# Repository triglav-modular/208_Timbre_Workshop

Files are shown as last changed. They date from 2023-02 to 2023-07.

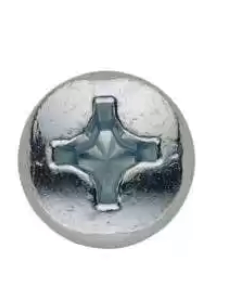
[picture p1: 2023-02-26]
Graphics/Links/208_timbre_2_6.png

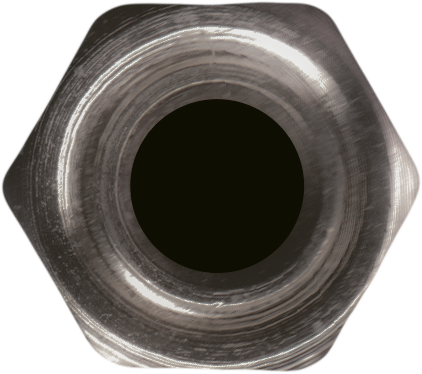
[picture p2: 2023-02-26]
Graphics/Links/208_timbre_2_4.png

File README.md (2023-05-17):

# 208 Timbre Workshop

Eurorack adaptation of the late 208 wavefolder section.

8 HP, adjustable input and output range.

208_Timbre_Workshop

BOM / Mouser cart: 
https://www.mouser.com/ProjectManager/ProjectDetail.aspx?AccessID=5e38aa6b9c

Sliders: https://hu.farnell.com/en-HU/alps/rs4511150k/potentiometer-slide-50k/dp/1191730

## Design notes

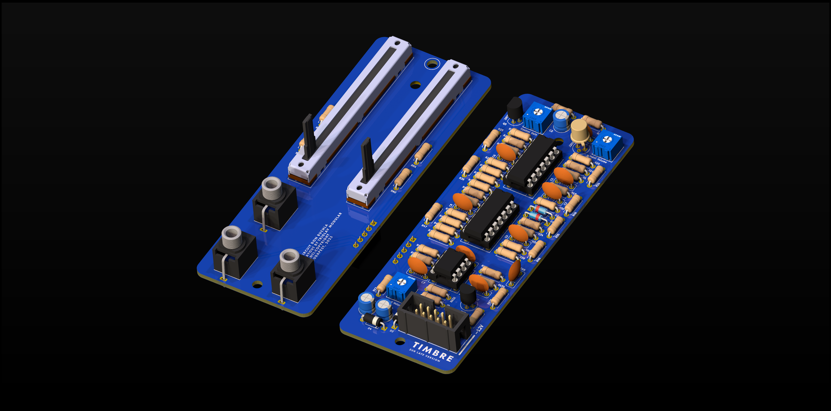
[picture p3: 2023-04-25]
Images/208_Timbre_Workshop.png

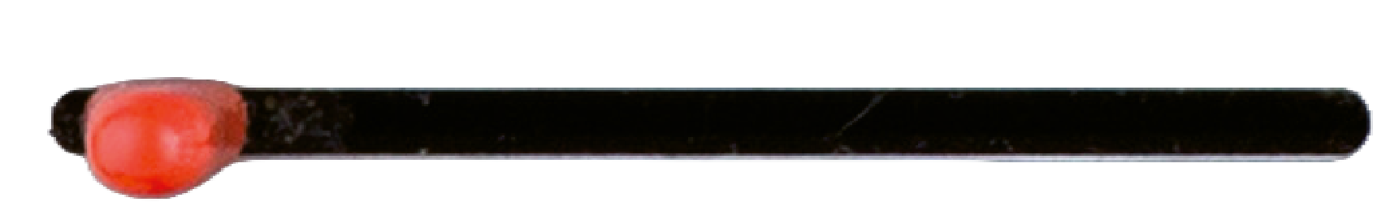
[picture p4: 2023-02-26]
Graphics/Links/208_timbre_2_1.png

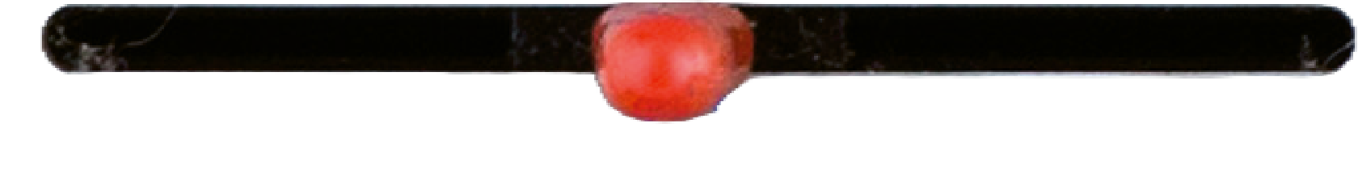
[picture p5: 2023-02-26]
Graphics/Links/208_timbre_2_2.png

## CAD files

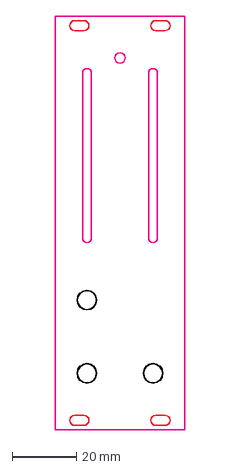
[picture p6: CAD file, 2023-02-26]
Graphics/panel_cut.dxf
40.3 x 128.5 mm

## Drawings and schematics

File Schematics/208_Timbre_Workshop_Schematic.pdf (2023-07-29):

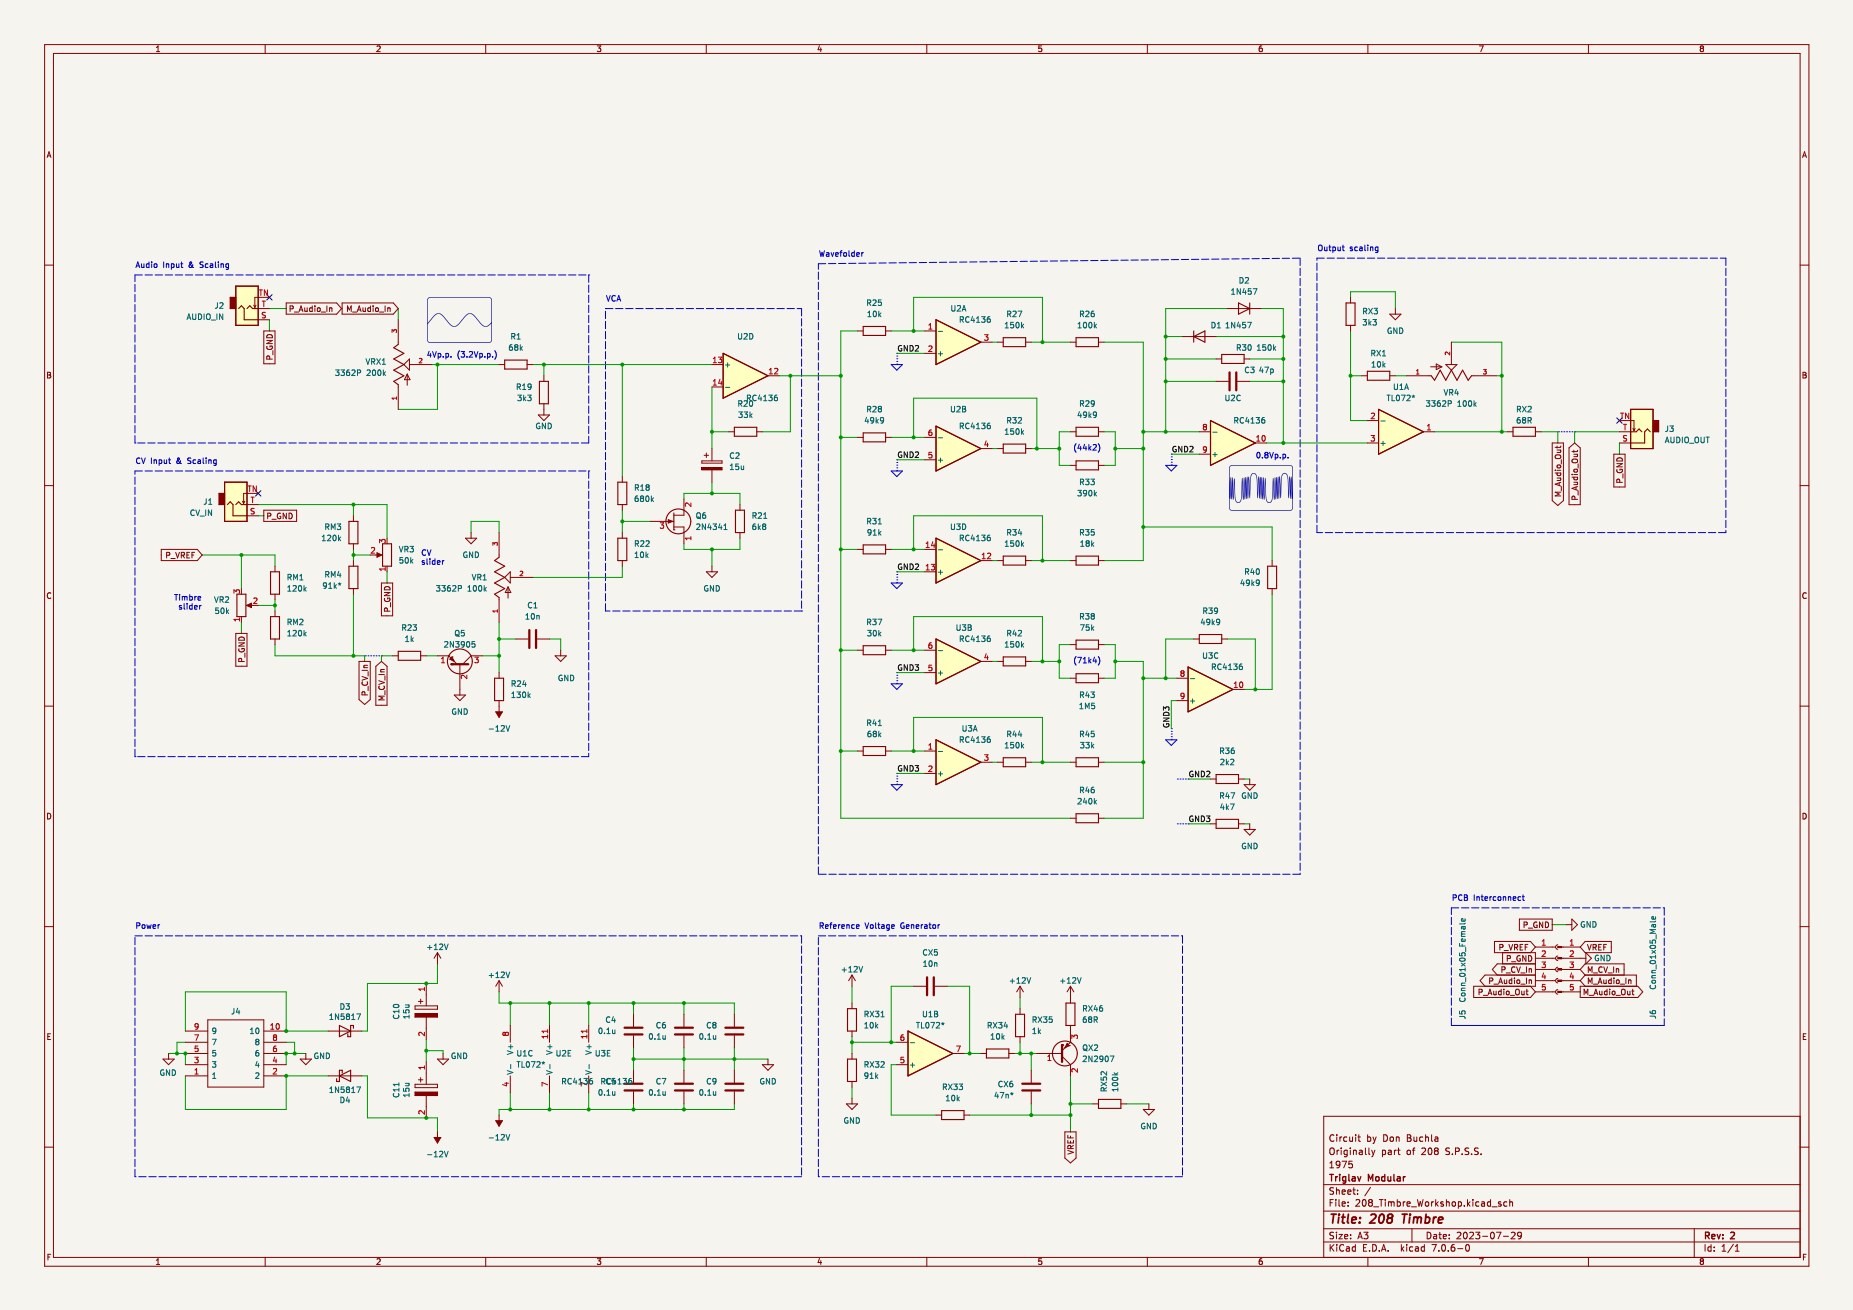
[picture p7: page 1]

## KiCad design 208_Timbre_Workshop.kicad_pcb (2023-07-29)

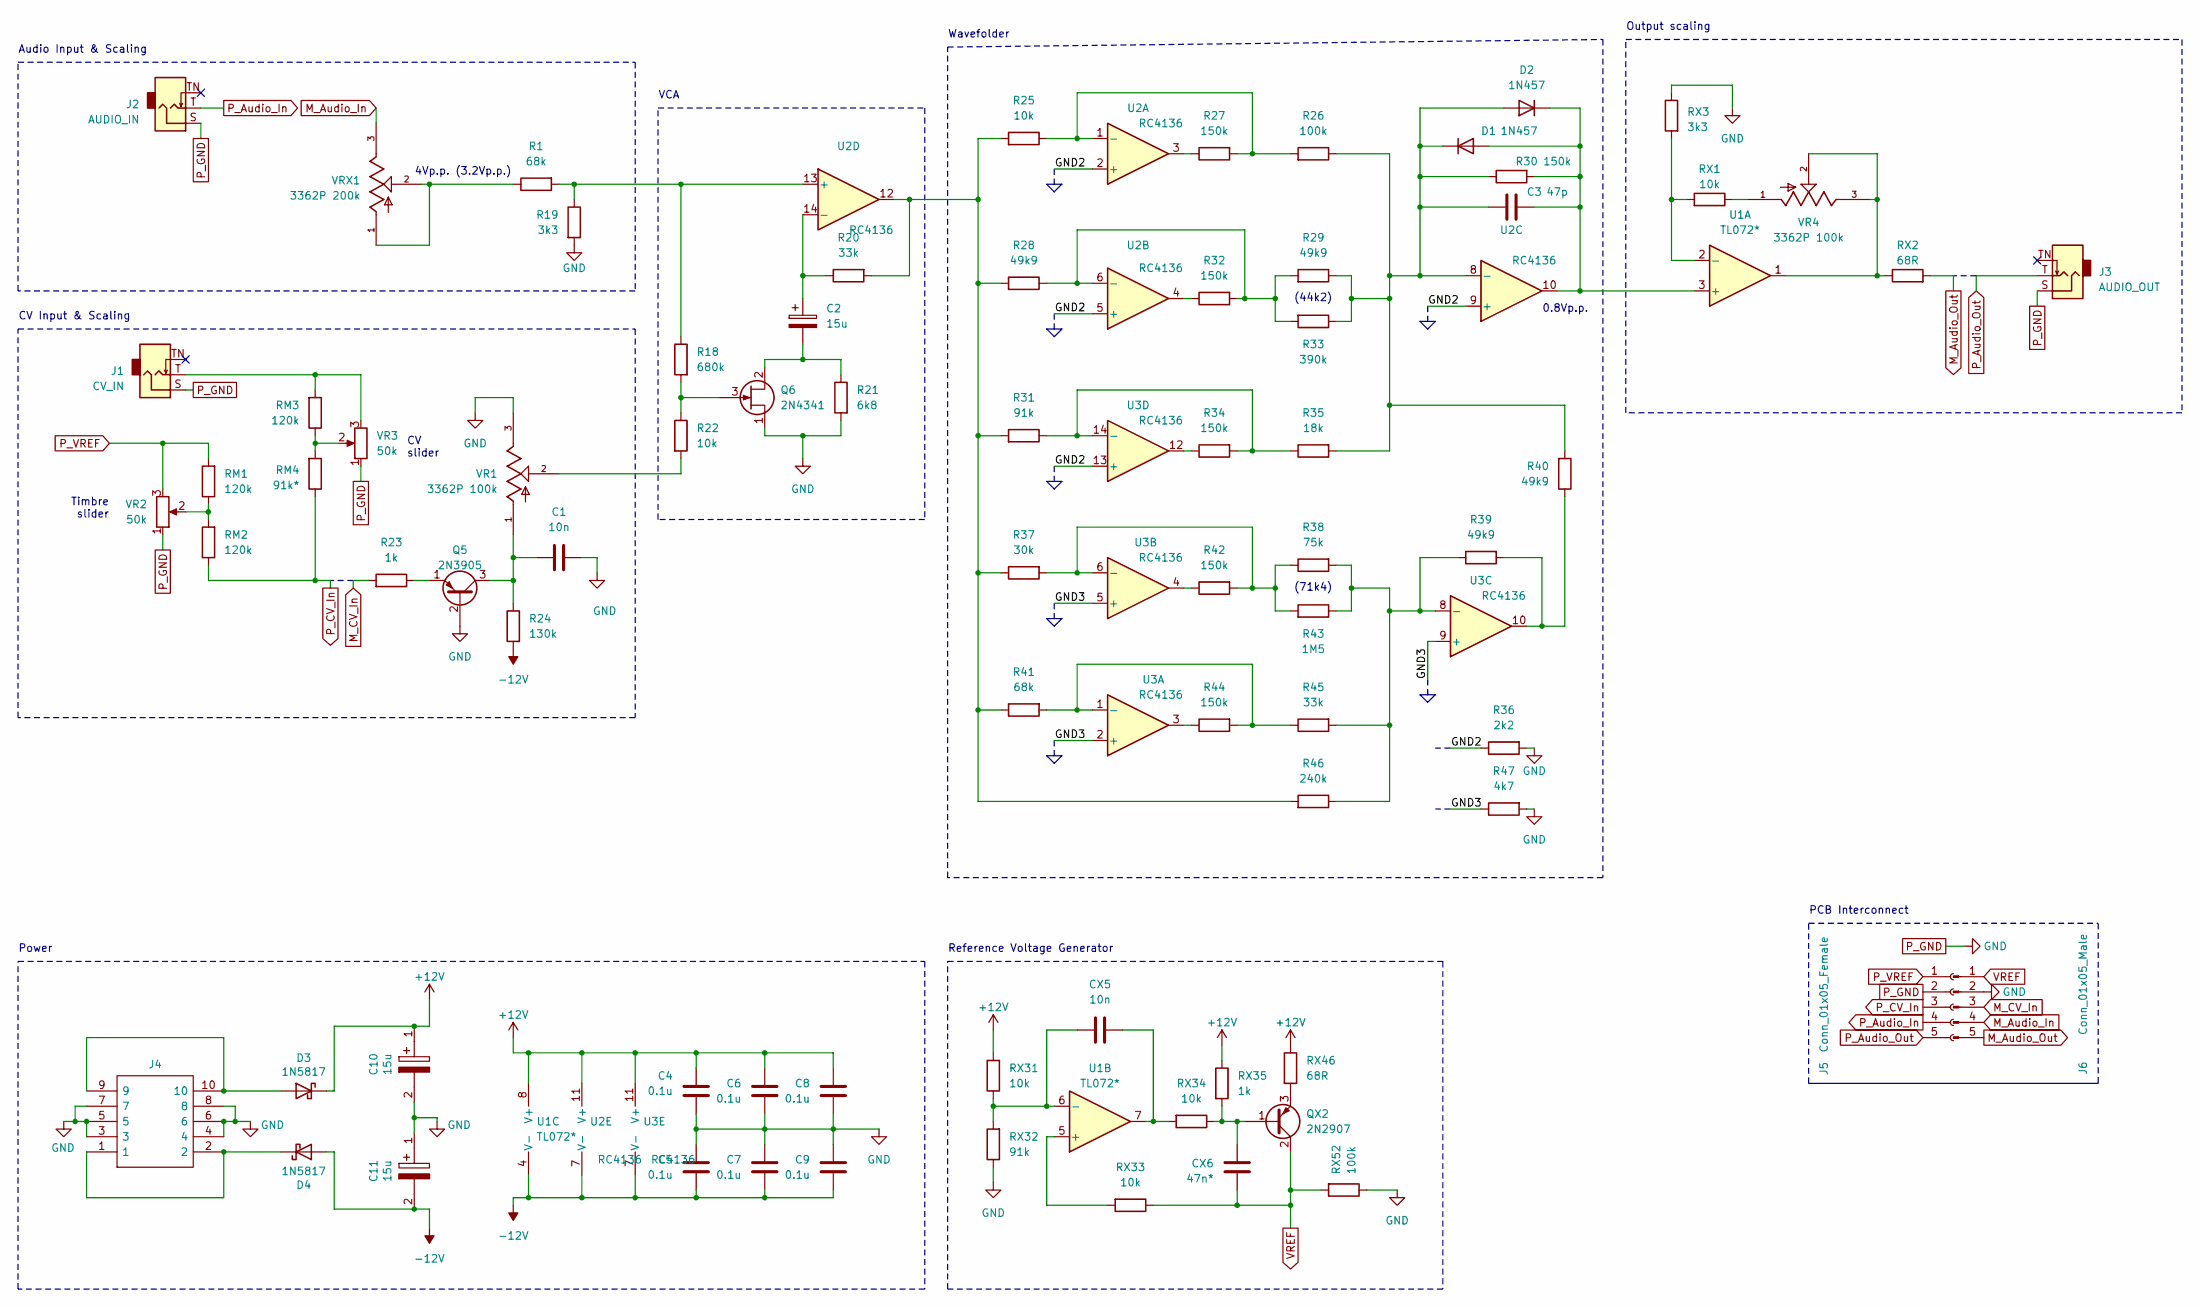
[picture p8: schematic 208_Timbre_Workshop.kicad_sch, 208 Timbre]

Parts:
C1: 10n; C_Disc_D7.0mm_W2.5mm_P5.00mm
C2: 15u; CP_Radial_D5.0mm_P2.00mm
C3: 47p; C_Disc_D7.0mm_W2.5mm_P5.00mm
C4, C5, C6, C7, C8, C9: 0.1u; C_Disc_D7.0mm_W2.5mm_P5.00mm
C10, C11: 15u; CP_Radial_D5.0mm_P2.00mm; Manufacturer_Part_Number EEE-FN1A470UR; Mouser Part Number 667-EEE-FN1A470UR
CX5: 10n; C_Disc_D7.0mm_W2.5mm_P5.00mm
CX6: 47n*; C_Disc_D7.0mm_W2.5mm_P5.00mm
D1, D2: 1N457; D_DO-35_SOD27_P7.62mm_Horizontal
D3, D4: 1N5817; D_DO-35_SOD27_P7.62mm_Horizontal
J1: CV_IN; THONKICONN
J2: AUDIO_IN; THONKICONN
J3: AUDIO_OUT; THONKICONN
J4: 30310-6002HB; Eurorack_Power; Manufacturer_Part_Number 30310-6002HB; Mouser Part Number 517-30310-6002
J5: Conn_01x05_Female; PinSocket_1x05_P2.54mm_Vertical
J6: Conn_01x05_Male; PinSocket_1x05_P2.54mm_Vertical
Q5: 2N3905; TO-92
Q6: 2N4341; TO-18-3
QX2: 2N2907; TO-92
R1, R41: 68k; R_Axial_DIN0207_L6.3mm_D2.5mm_P7.62mm_Horizontal
R18: 680k; R_Axial_DIN0207_L6.3mm_D2.5mm_P7.62mm_Horizontal
R19: 3k3; R_Axial_DIN0207_L6.3mm_D2.5mm_P7.62mm_Horizontal
R20, R45: 33k; R_Axial_DIN0207_L6.3mm_D2.5mm_P7.62mm_Horizontal
R21: 6k8; R_Axial_DIN0207_L6.3mm_D2.5mm_P7.62mm_Horizontal
R22, R25: 10k; R_Axial_DIN0207_L6.3mm_D2.5mm_P7.62mm_Horizontal
R23: 1k; R_Axial_DIN0207_L6.3mm_D2.5mm_P7.62mm_Horizontal
R24: 130k; R_Axial_DIN0207_L6.3mm_D2.5mm_P7.62mm_Horizontal
R26: 100k; R_Axial_DIN0207_L6.3mm_D2.5mm_P7.62mm_Horizontal
R27, R30, R32, R34, R42, R44: 150k; R_Axial_DIN0207_L6.3mm_D2.5mm_P7.62mm_Horizontal
R28, R29, R39, R40: 49k9; R_Axial_DIN0207_L6.3mm_D2.5mm_P7.62mm_Horizontal
R31: 91k; R_Axial_DIN0207_L6.3mm_D2.5mm_P7.62mm_Horizontal
R33: 390k; R_Axial_DIN0207_L6.3mm_D2.5mm_P7.62mm_Horizontal
R35: 18k; R_Axial_DIN0207_L6.3mm_D2.5mm_P7.62mm_Horizontal
R36: 2k2; R_Axial_DIN0207_L6.3mm_D2.5mm_P7.62mm_Horizontal
R37: 30k; R_Axial_DIN0207_L6.3mm_D2.5mm_P7.62mm_Horizontal
R38: 75k; R_Axial_DIN0207_L6.3mm_D2.5mm_P7.62mm_Horizontal
R43: 1M5; R_Axial_DIN0207_L6.3mm_D2.5mm_P7.62mm_Horizontal
R46: 240k; R_Axial_DIN0207_L6.3mm_D2.5mm_P7.62mm_Horizontal
R47: 4k7; R_Axial_DIN0207_L6.3mm_D2.5mm_P7.62mm_Horizontal
RM1, RM2, RM3: 120k; R_Axial_DIN0207_L6.3mm_D2.5mm_P7.62mm_Horizontal
RM4: 91k*; R_Axial_DIN0207_L6.3mm_D2.5mm_P7.62mm_Horizontal
RX1, RX31, RX33, RX34: 10k; R_Axial_DIN0207_L6.3mm_D2.5mm_P7.62mm_Horizontal
RX2, RX46: 68R; R_Axial_DIN0207_L6.3mm_D2.5mm_P7.62mm_Horizontal
RX3: 3k3; R_Axial_DIN0207_L6.3mm_D2.5mm_P7.62mm_Horizontal
RX32: 91k; R_Axial_DIN0207_L6.3mm_D2.5mm_P7.62mm_Horizontal
RX35: 1k; R_Axial_DIN0207_L6.3mm_D2.5mm_P7.62mm_Horizontal
RX52: 100k; R_Axial_DIN0207_L6.3mm_D2.5mm_P7.62mm_Horizontal
U1: TL072*; DIP-8_W7.62mm_Socket
U2, U3: RC4136; DIP-14_W7.62mm_Socket
VR1, VR4: 3362P 100k; BOURNS_3362P_TRIMMER; PARTREV 08/26/10
VR2, VR3: 50k; RS45111
VRX1: 3362P 200k; BOURNS_3362P_TRIMMER; PARTREV 08/26/10

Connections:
+12V: C4.2, C6.2, C8.2, C10.1, D3.1 (K), RX31.2, RX35.1, RX46.1, U1.8 (V+), U2.11 (V+), U3.11 (V+)
-12V: C5.1, C7.1, C9.1, C11.2, D4.2 (A), R24.2, U1.4 (V-), U2.7 (V-), U3.7 (V-)
/GND2: R36.1, U2.2 (+), U2.5 (+), U2.9 (+), U3.13 (+)
/GND3: R47.1, U3.2 (+), U3.5 (+), U3.9 (+)
M_Audio_In: J6.4, VRX1.3
M_Audio_Out: J6.5, RX2.2
M_CV_In: J6.3, R23.2
unnamed: CX5.2, RX34.2, U1.7
unnamed: C3.2, D1.2 (A), D2.1 (K), R30.2, U1.3 (+), U2.10
unnamed: C3.1, D1.1 (K), D2.2 (A), R26.1, R29.1, R30.1, R33.1, R35.2, R40.2, U2.8 (-)
unnamed: D3.2 (A), J4.9, J4.10
unnamed: D4.1 (K), J4.1, J4.2
unnamed: J1.T, RM3.2, VR3.3
unnamed: C1.1, Q5.3 (C), R24.1, VR1.1
unnamed: Q5.1 (E), R23.1
unnamed: C2.2, Q6.2 (D), R21.1
unnamed: Q6.3 (G), R18.2, R22.1
unnamed: CX6.2, QX2.1 (B), RX34.1, RX35.2
unnamed: QX2.3 (E), RX46.2
unnamed: R1.1, VRX1.1, VRX1.2
unnamed: R20.2, R25.2, R28.2, R31.2, R37.1, R41.1, R46.2, U2.12
unnamed: R22.2, VR1.2
unnamed: R27.1, U2.3
unnamed: R32.1, U2.4
unnamed: R34.1, U3.12
unnamed: R39.2, R40.1, U3.10
unnamed: R42.1, U3.4
unnamed: R44.1, U3.3
unnamed: RM1.1, RM2.2, VR2.2
unnamed: RM3.1, RM4.2, VR3.2
unnamed: RX1.1, VR4.1
unnamed: RX2.1, U1.1, VR4.2, VR4.3
unnamed: RX1.2, RX3.2, U1.2 (-)
unnamed: RX33.2, U1.5 (+)
unnamed: CX5.1, RX31.1, RX32.2, U1.6 (-)
unnamed: R25.1, R26.2, R27.2, U2.1 (-)
unnamed: R28.1, R29.2, R32.2, R33.2, U2.6 (-)
unnamed: R1.2, R18.1, R19.1, U2.13 (+)
unnamed: C2.1, R20.1, U2.14 (-)
unnamed: R41.2, R44.2, R45.1, U3.1 (-)
unnamed: R37.2, R38.1, R42.2, R43.2, U3.6 (-)
unnamed: R38.2, R39.1, R43.1, R45.2, R46.1, U3.8 (-)
unnamed: R31.1, R34.2, R35.1, U3.14 (-)
P_Audio_In: J2.T, J5.4
P_Audio_Out: J3.T, J5.5
P_CV_In: J5.3, RM2.1, RM4.1
P_GND: C1.2, C4.1, C5.2, C6.1, C7.2, C8.1, C9.2, C10.2, C11.1, J1.S, J2.S, J3.S, J4.3, J4.4, J4.5, J4.6, J4.7, J4.8, J5.2, J6.2, Q5.2 (B), Q6.1 (S), R19.2, R21.2, R36.2, R47.2, RX3.1, RX32.1, RX52.1, VR1.3, VR2.1, VR3.1
P_VREF: J5.1, RM1.2, VR2.3
VREF: CX6.1, J6.1, QX2.2 (C), RX33.1, RX52.2

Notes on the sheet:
4Vp.p. (3.2Vp.p.)
Timbre slider
Wavefolder
PCB Interconnect
Power
CV slider
Reference Voltage Generator
VCA
(71k4)
Output scaling
CV Input & Scaling
0.8Vp.p.
Audio Input & Scaling
(44k2)

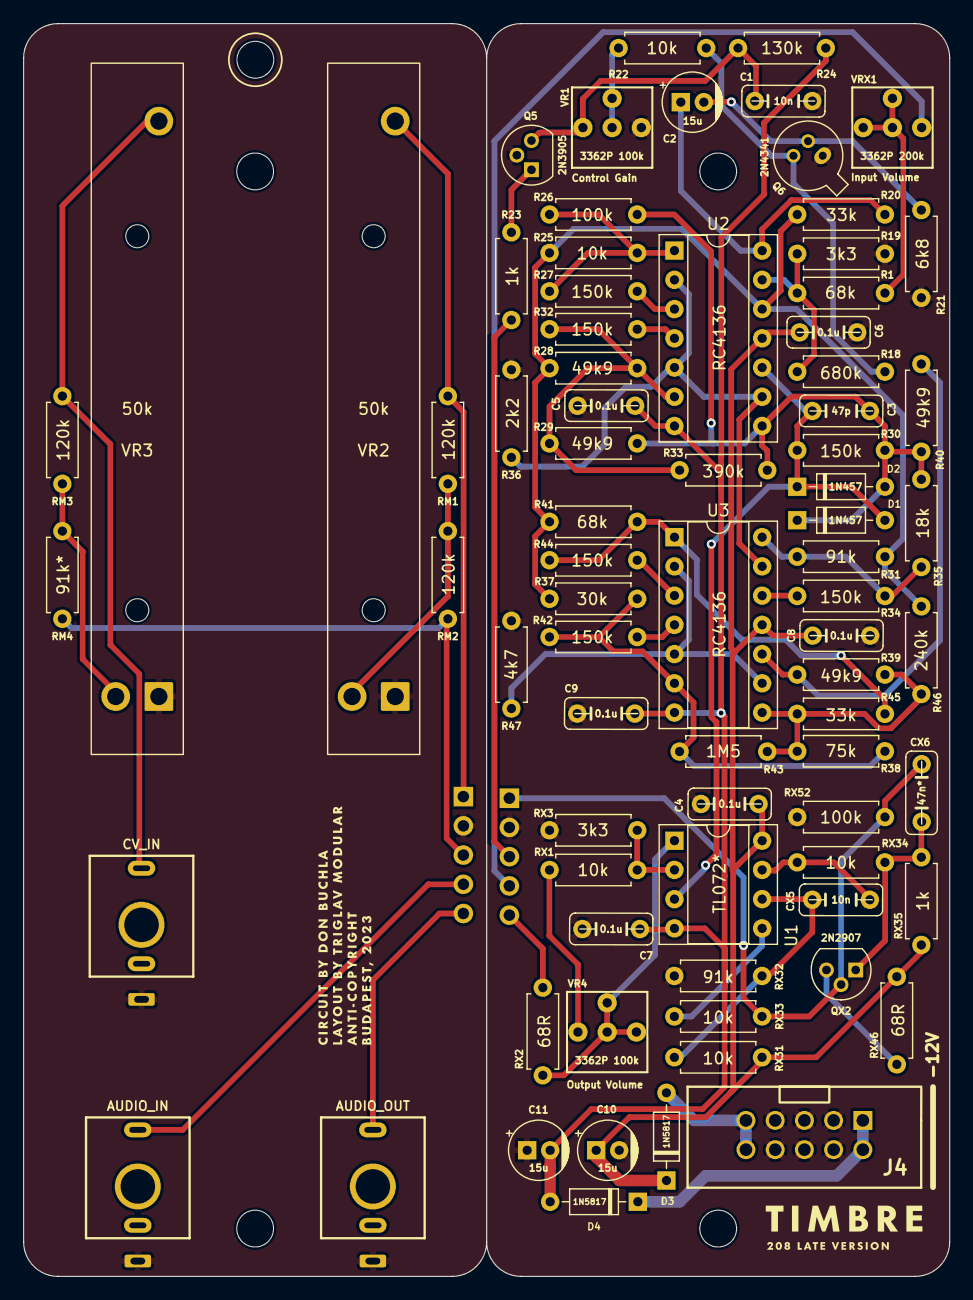
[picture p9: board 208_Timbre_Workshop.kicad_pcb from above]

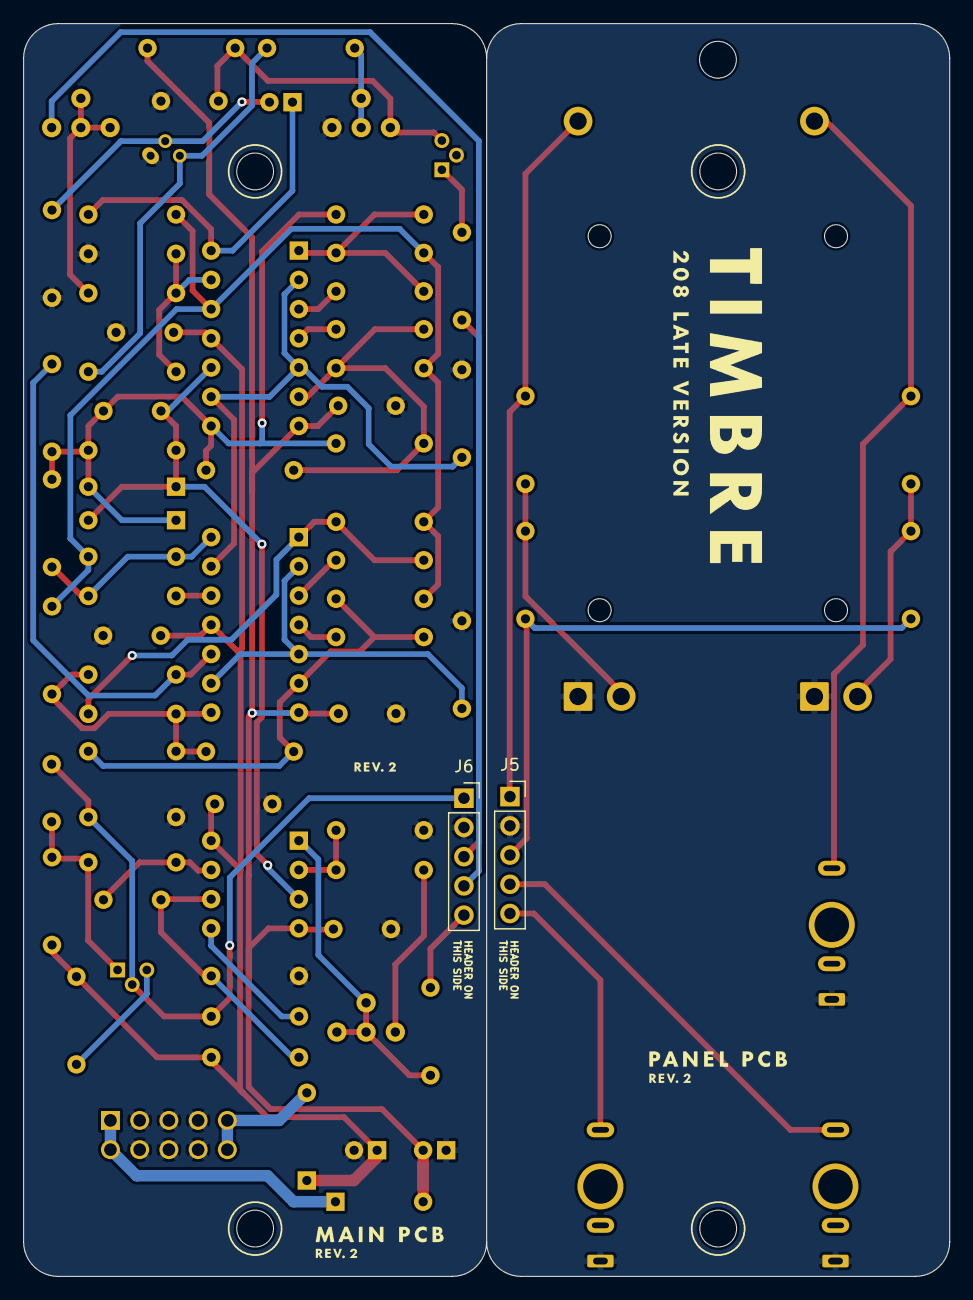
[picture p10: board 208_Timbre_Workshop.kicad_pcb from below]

Board: 2 copper layers, 80.5 x 108.9 mm, 79 parts (2 on the bottom side), 49 nets.

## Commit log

2023-03-18 alignment, transistor pins
    [208_Timbre_Workshop.kicad_pcb, 208_Timbre_Workshop.kicad_sch, 208_Timbre_Workshop_Panel.kicad_pcb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]
2023-04-26 Schematic update
2023-05-11 transistor update
    [208_Timbre_Workshop.kicad_pcb, 208_Timbre_Workshop.kicad_sch]
2023-07-29 Rev. 2
    [208_Timbre_Workshop.kicad_pcb, 208_Timbre_Workshop.kicad_sch]
